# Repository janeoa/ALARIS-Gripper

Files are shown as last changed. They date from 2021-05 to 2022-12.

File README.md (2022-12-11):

# ALARIS Gripper project

* Mechanics
* Software
* PCBs

## GUI
The GUI is written in Go using Fyne. To run type `go run .` from `/GUI` directory

### binary
As every Go project can, you can build the project with `go build .`

### Dependancies
The `go.mod` file contains references for all used dependancies and you can download them with `go get .`

### Link to the Drive with the Model
There are two models presented: Solidworks and STL.
https://drive.google.com/file/d/1LMuIjnykMAK1zOiwv8W7WpgrKtq3R2hT/view?usp=sharing

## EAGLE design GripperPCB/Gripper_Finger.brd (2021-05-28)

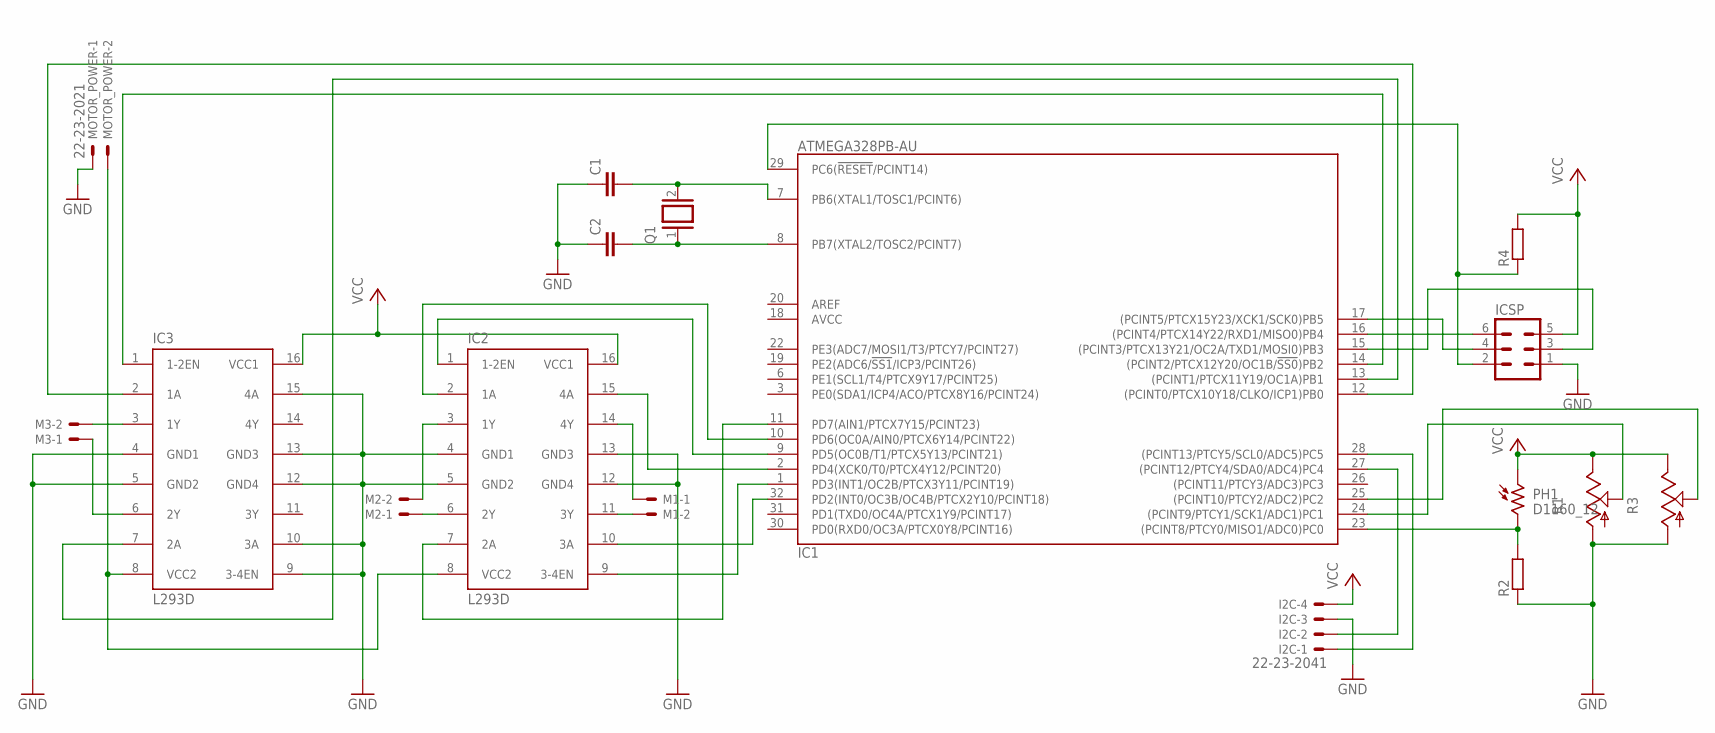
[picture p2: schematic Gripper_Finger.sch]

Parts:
C1, C2: C2.5/2; C2.5-2
I2C: 22-23-2041
IC1: ATMEGA328PB-AU; QFP32_7X7_0.80
IC2, IC3: L293D; DIL16
ICSP: MA03-2
M1, M2, M3: 22-23-2021
MOTOR_POWER: 22-23-2021
PH1: D1160_12; D11XX
Q1: XTAL/S; QS
R1, R3: TRIM_US-B64Y; B64Y
R2, R4: R-EU_0204/5; 0204/5

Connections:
AVCC: IC1.18 (AVCC)
CRYSTAL1: C2.2, IC1.8 (PB7(XTAL2/TOSC2/PCINT7)), Q1.1
CRYSTAL2: C1.2, IC1.7 (PB6(XTAL1/TOSC1/PCINT6)), Q1.2
GND: C1.1, C2.1, I2C.3, IC1.5 (GND), IC1.21 (GND), IC2.4 (GND1), IC2.5 (GND2), IC2.12 (GND4), IC2.13 (GND3), IC3.4 (GND1), IC3.5 (GND2), IC3.9 (3-4EN), IC3.10 (3A), IC3.12 (GND4), IC3.13 (GND3), IC3.15 (4A), ICSP.1, MOTOR_POWER.1, R1.A, R2.1, R3.A
LIGHT: IC1.23 ((PCINT8/PTCY0/MISO1/ADC0)PC0), PH1.2, R2.2
M1A: IC2.14 (4Y), M1.1
M1ASIG: IC1.2 (PD4(XCK0/T0/PTCX4Y12/PCINT20)), IC2.15 (4A)
M1B: IC2.11 (3Y), M1.2
M1BSIG: IC1.32 (PD2(INT0/OC3B/OC4B/PTCX2Y10/PCINT18)), IC2.10 (3A)
M1E: IC1.1 (PD3(INT1/OC2B/PTCX3Y11/PCINT19)), IC2.9 (3-4EN)
M2A: IC2.3 (1Y), M2.2
M2ASIG: IC1.10 (PD6(OC0A/AIN0/PTCX6Y14/PCINT22)), IC2.2 (1A)
M2B: IC2.6 (2Y), M2.1
M2BSIG: IC1.11 (PD7(AIN1/PTCX7Y15/PCINT23)), IC2.7 (2A)
M2E: IC1.9 (PD5(OC0B/T1/PTCX5Y13/PCINT21)), IC2.1 (1-2EN)
M3A: IC3.6 (2Y), M3.1
M3ASIG: IC1.13 ((PCINT1/PTCX11Y19/OC1A)PB1), IC3.7 (2A)
M3B: IC3.3 (1Y), M3.2
M3BSIG: IC1.12 ((PCINT0/PTCX10Y18/CLKO/ICP1)PB0), IC3.2 (1A)
M3E: IC1.14 ((PCINT2/PTCX12Y20/OC1B/!SS0!)PB2), IC3.1 (1-2EN)
MISO: IC1.16 ((PCINT4/PTCX14Y22/RXD1/MISO0)PB4), ICSP.6
MOSI: IC1.15 ((PCINT3/PTCX13Y21/OC2A/TXD1/MOSI0)PB3), ICSP.3
MOTOR_POWER: IC2.8 (VCC2), IC3.8 (VCC2), MOTOR_POWER.2
POT1: IC1.24 ((PCINT9/PTCY1/SCK1/ADC1)PC1), R1.S
POT2: IC1.25 ((PCINT10/PTCY2/ADC2)PC2), R3.S
RESET: IC1.29 (PC6(!RESET!/PCINT14)), ICSP.2, R4.1
SCK: IC1.17 ((PCINT5/PTCX15Y23/XCK1/SCK0)PB5), ICSP.4
SCL: I2C.1, IC1.28 ((PCINT13/PTCY5/SCL0/ADC5)PC5)
SDA: I2C.2, IC1.27 ((PCINT12/PTCY4/SDA0/ADC4)PC4)
VCC: I2C.4, IC1.4 (VCC), IC2.16 (VCC1), IC3.16 (VCC1), ICSP.5, PH1.1, R1.E, R3.E, R4.2

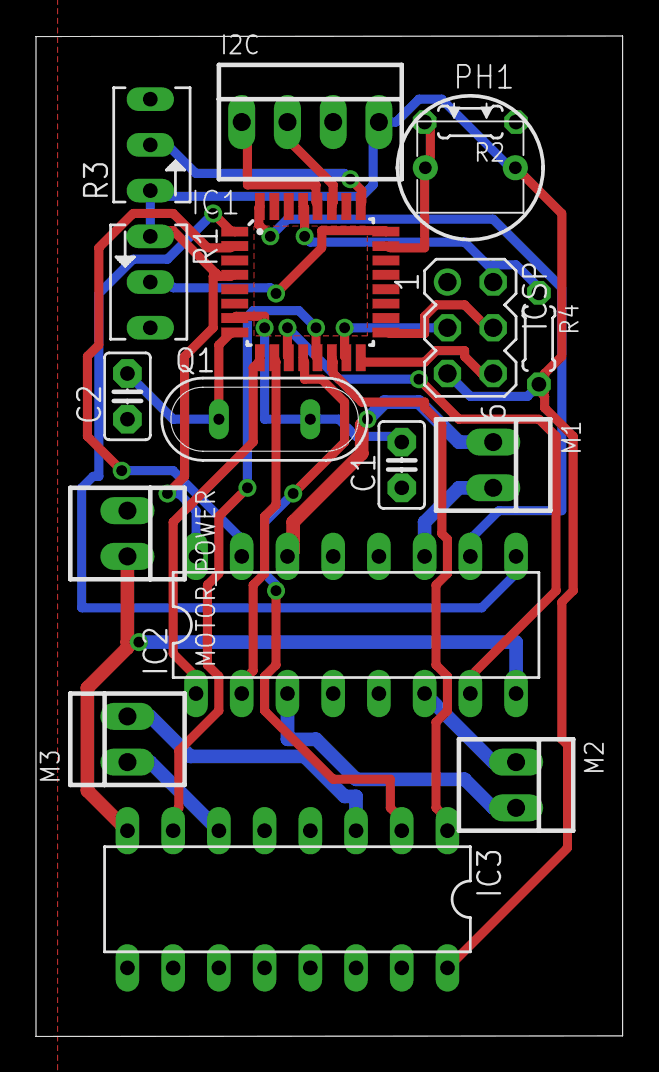
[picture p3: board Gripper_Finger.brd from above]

Board: 2 copper layers, 32.6 x 55.6 mm, 17 parts (0 on the bottom side), 29 nets.

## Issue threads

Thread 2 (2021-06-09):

Store last position on EEPROM

janeoa, 2021-06-09:
- [ ] Try EEPROM example
- [ ] Read about EEPROM weaknesses
- [ ] Store curr pos into EEPROM
- [ ] Read EEPROM on boot
- [ ] Serial Print curr on boot

janeoa, 2021-06-09:
Issue по сути просто для обмена идеями на счет задач в карточках. Если есть идеи/комментарии - пиши сюда

janeoa, 2021-06-09:
@Sansei-CPP

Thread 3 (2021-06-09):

Протокол связи руки с пальцами (езда по ледам)

janeoa, 2021-06-09:
Как и что должна отправлять рука по i2c пальцам. Пока хз. По мере прогресса буду добавлять описание тут

- [x] check finger state
- [x] send new state to fingers

Closed 2021-06-18.

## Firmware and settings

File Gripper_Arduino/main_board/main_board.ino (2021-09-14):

#include <Wire.h>
#include <EasyTransfer.h>
#include <EasyTransferI2C.h>
#include "Lights.h"

EasyTransfer ETfromPCtoMain, ETfromMainToPC; 
EasyTransferI2C ETfromMainToFinger; 
EasyTransferI2C ETfromFingerToMain;


struct PC_TO_MAIN{
  byte id;
  byte pos;
  byte A;
  byte B;
};

struct MAIN_TO_PC{
  byte id;
  byte pos;
  byte A;
  byte B;
};

struct SEND_DATA_STRUCTURE{
  byte dir;
  byte A;
  byte B;
};

struct RECIEVE_FINGER_STATE{
  byte id;
  byte A;
  byte B;
};

PC_TO_MAIN dataFromPC;
MAIN_TO_PC dataToPC;

SEND_DATA_STRUCTURE dataToFinger;
RECIEVE_FINGER_STATE dataFromFinger;
bool is_next_on_right(int prev, int curr);

const byte pins[] = {2,3,4,5,6,7,8,9};

Lights lights(pins);
byte foundSlaves[8] = {255,255,255,255,255,255,255,255};
byte prev[8] = {255,255,255,255,255,255,255,255};

void setup() {
  Serial.begin(115200);  // start serial for output
  Serial.println(F("init"));
  ETfromPCtoMain.begin(details(dataFromPC), &Serial);
  ETfromMainToPC.begin(details(dataToPC), &Serial);
//  Wire.setClock(10000);
  Wire.begin(69);        // join i2c bus (address optional for master)
  Wire.onReceive(receive);
  ETfromMainToFinger.begin(details(dataToFinger), &Wire);
  ETfromFingerToMain.begin(details(dataFromFinger), &Wire);
  for (byte i=0; i<8; i++){
    pinMode(pins[i], OUTPUT);
  }
  delay(100);
  for (byte i=0; i<8; i++){
    digitalWrite(pins[i], HIGH);
    delay(100);
    digitalWrite(pins[i], LOW);
  }
//
////  Serial.println("searching for slaves");
  for (byte i = 0; i < 8; i++) {
    Wire.beginTransmission(i);
    if (Wire.endTransmission() == 0) {
      foundSlaves[i] = i;
      prev[i] = i;
    }
  }
}

void receive(int numBytes) {}

byte slaveCallIndex = 0;
unsigned long last = millis();

void loop() {
//  if(millis()-last>200){
//    last = millis();
//    dataToFinger.dir = 69;
//    if(foundSlaves[slaveCallIndex] != 255){
//      ETfromMainToFinger.sendData(slaveCallIndex);
//    }
//    slaveCallIndex = (slaveCallIndex==7)?0:slaveCallIndex+1;
//  }
  if(ETfromPCtoMain.receiveData()){
    digitalWrite(pins[prev[dataFromPC.id]], LOW);
    digitalWrite(pins[dataFromPC.pos], HIGH);
    delay(50);
    prev[dataFromPC.id] = dataFromPC.pos;
    if(foundSlaves[dataFromPC.id] != dataFromPC.pos){
      dataToFinger.dir = is_next_on_right(foundSlaves[dataFromPC.id], dataFromPC.pos)?0:1;//dataFromPC.pos;
    }else{
//      digitalWrite(pins[dataFromPC.pos], LOW);
      dataToFinger.dir = 255;
    }
    
    dataToFinger.A = dataFromPC.A;
    dataToFinger.B = dataFromPC.B;
    ETfromMainToFinger.sendData(dataFromPC.id);

    foundSlaves[dataFromPC.id] = dataFromPC.pos;
  }
  
  if(ETfromFingerToMain.receiveData()){
    dataToPC.id   = dataFromFinger.id;
    dataToPC.pos  = foundSlaves[dataFromFinger.id];//dataFromFinger.pos;   
    dataToPC.A    = dataFromFinger.A;
    dataToPC.B    = dataFromFinger.B;
    ETfromMainToPC.sendData();
  }else{
    for(byte i=0; i<8; i++){
      if(foundSlaves[i]<255){
        dataToPC.id = i;
        dataToPC.pos = foundSlaves[i];   
        dataToPC.A = 255;
        ETfromMainToPC.sendData();
      }
    }
  }
//  delay(250);
}

//void checkFingerState(byte finger_id){
//  
//  const byte bufflen = 10;
//  byte readbuf[bufflen];
//  Wire.requestFrom(finger_id, bufflen);
//  bool got_data = false;
//  
//  byte binex = 0;
//  while(Wire.available()){
//    got_data = true;
//    readbuf[binex++] = Wire.read(); // receive a byte as character
//  }
//
//  if(got_data){
//    int aa,bb,cc,dd;
//    memcpy((int*)&aa  , readbuf+2, 2);
//    memcpy((int*)&bb  , readbuf+4, 2);
//    memcpy((int*)&cc  , readbuf+6, 2);
//    memcpy((int*)&dd  , readbuf+8, 2);
//    char msg[20];
//  }
//}

bool is_next_on_right(int prev, int curr){
  bool is_right = false;
  
  int delta = curr - prev;
  if(delta > 0 && delta < 4) is_right = true;
  if(delta < -4 && delta > -8) is_right = true;
  return is_right;
}
//void dexDump(char *in, int len){
//  Serial.print(">>");
//  for(int i=0; i<len; i++){
//    printHex(in[i]);
//  }
//  Serial.println("<<");
//}
//
//void printHex(uint8_t num) {
//  char hexCar[2];
//
//  sprintf(hexCar, "%02X", num);
//  Serial.print(hexCar);
//}
//
//unsigned char ToByte(bool b[8])
//{
//    unsigned char c = 0;
//    for (int i=0; i < 8; ++i)
//        if (b[i])
//            c |= 1 << i;
//    return c;
//}

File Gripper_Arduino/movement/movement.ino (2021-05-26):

#define READY 0
#define MOVE 1
#define CALIB 2

// Motor A connections
int enA = 13;
int in1 = 12;
int in2 = 11;
int lightCalib;
int sensorValue;

int state = CALIB;

//resistance drops, we can check changes in analogread
int sensorPin = A0; // select the input pin for LDR

int lightCal;

int pstn = 0; // for incoming serial data
int prev = 0;

void setup() {
  Serial.begin(9600); 
  pinMode(9, OUTPUT);
  pinMode(8, OUTPUT);
  pinMode(7, OUTPUT);
  pinMode(6, OUTPUT);
  pinMode(5, OUTPUT);
  pinMode(4, OUTPUT);
  pinMode(3, OUTPUT);
  pinMode(2, OUTPUT);
  
  // Set all the motor control pins to outputs
  pinMode(enA, OUTPUT);
  pinMode(in1, OUTPUT);
  pinMode(in2, OUTPUT);
  
  // Turn off motors - Initial state
  digitalWrite(in1, LOW);
  digitalWrite(in2, LOW);

  pinMode(sensorPin, INPUT);
  lightCal = analogRead(sensorPin);
}

void loop() {
  if(state == CALIB){
    analogWrite(enA, 255);
    digitalWrite(in1, HIGH);
    digitalWrite(in2, LOW);
    delay(2000);
    digitalWrite(in1, LOW);
    digitalWrite(in2, HIGH);
    delay(2000);
    digitalWrite(in1, LOW);
    digitalWrite(in2, LOW);
    
    lightCalib = analogRead(sensorPin);
    Serial.println(sensorValue);
    state = READY;    
  }
  if (Serial.available()>= 1){
    pstn = Serial.parseInt(); 
    Serial.print("I received: ");
    Serial.println(pstn);
    digitalWrite(pstn, HIGH);
    digitalWrite(prev, LOW);
    prev = pstn;
    state = MOVE;
    }             // wait for user input
  if(state == MOVE){
  sensorValue = analogRead(sensorPin); // read the value from the sensor
  Serial.println(sensorValue); //prints the values coming from the sensor on the screen
    if (sensorValue < lightCalib + 100){
       directionControl();
       state = READY;
       Serial.println("found");
  }
  else if (sensorValue > lightCalib + 100) {
    digitalWrite(in1, LOW);
    digitalWrite(in2, LOW);
  }
  }
  else {
    digitalWrite(in1, LOW);
    digitalWrite(in2, LOW);    
  }
}

// This function lets you control spinning direction of motors
void directionControl() {
  // Set motors to maximum speed
  // For PWM maximum possible values are 0 to 255
  analogWrite(enA, 255);

  // Turn on motor A & B
  digitalWrite(in1, HIGH);
  digitalWrite(in2, LOW);
  delay(2000);
}

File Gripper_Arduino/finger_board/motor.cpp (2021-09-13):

#include "Arduino.h"
#include "Motor.h"

#define tolerance 20

Motor::Motor(int pinA, int pinB, int pinE, int anal, int minp, int maxp){
  _pinA = pinA;
  _pinB = pinB;
  _pinE = pinE;
  _anal = anal;
  _minp = minp;
  _maxp = maxp;

  pinMode(pinA, OUTPUT);
  pinMode(pinB, OUTPUT);
  pinMode(pinE, OUTPUT);
  digitalWrite(pinE, HIGH);
}

void Motor::setGoal(int goal){
  if(0<=goal && goal<=100){
    _goal = map(goal, 0, 100, _minp, _maxp);
  }
}

void Motor::tick(){
  _rawadc = analogRead(_anal);
  if(_goal > _rawadc - tolerance && _goal < _rawadc + tolerance){
    digitalWrite(_pinA, LOW);
    digitalWrite(_pinB, LOW);
  }else if(_goal > _rawadc){
    digitalWrite(_pinA, HIGH);
    digitalWrite(_pinB, LOW);
  }else{
    digitalWrite(_pinA, LOW);
    digitalWrite(_pinB, HIGH);
  }
}

int Motor::getPos(){
  _rawadc = analogRead(_anal);
//  Serial.print("EPTA");
//  Serial.println(_anal);
  return map(_rawadc, _minp, _maxp, 0, 100);;
}

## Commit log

2021-05-24 Eagle PCB init
    [Gripper_Finger.brd, Gripper_Finger.sch]
2021-05-24 Arduino i2c init
2021-05-24 motor class
2021-05-24 board update with l293d
    [Gripper_Finger.brd, Gripper_Finger.sch]
2021-05-24 version 1.0.0 sent to engineering
    [Gripper_Finger.brd, Gripper_Finger.sch]
2021-05-25 Update ledposition.ino
    Final Version
2021-05-26 added crystal
    [Gripper_Finger.brd, Gripper_Finger.sch]
2021-05-26 layout with hole in rastnet under the uC
    [Gripper_Finger.brd]
2021-05-27 Я создал отдельным проектам отдельные папки
2021-05-27 tried I2C w/o crystal
2021-05-28 не помню :D
    [Gripper_Finger.brd]
2021-06-03 direction of finger
2021-06-03 dir func calc excel
    [dir_calc.xlsx]
2021-06-03 Slave roller motor class
2021-06-09 fixed issue with single digid requests
    [main_board.ino]
2021-06-16 i2c sensor connection established. bug on Serial
    [finger_board.ino, main_board.ino, motor.cpp]
2021-06-18 threshold to hard 400
    no calibration
2021-06-18 debug data via i2c
2021-06-18 finger 10 bit throttled data exchange
2021-06-22 Simple layout of finger list
2021-06-23 finger pos + circle
2021-06-27 send/reset buttons on bottom
2021-06-28 made two files and Gripper struct
2021-06-28 auto reconnect device
2021-07-02 set/reset active finger
2021-07-07 temporary no UART device list log
2021-07-08 ADD: reset button func
2021-09-07 EasyTransfer finger position
2021-09-08 FIN: EasyTransfer for finger
2021-09-13 FIN: sync work TODO: light sensor calib
2021-09-14 FIN: rott done. all work todo: fix stuck motors
    [Roller.h, finger_board.ino, main_board.ino]
